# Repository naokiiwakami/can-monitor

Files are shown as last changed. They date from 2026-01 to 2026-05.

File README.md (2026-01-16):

# CAN Monitor

This is a project to build a simple CAN bus monitor.
The module uses an FTDI compatible USB to UART adapter for interface to PC
as well as power supply.

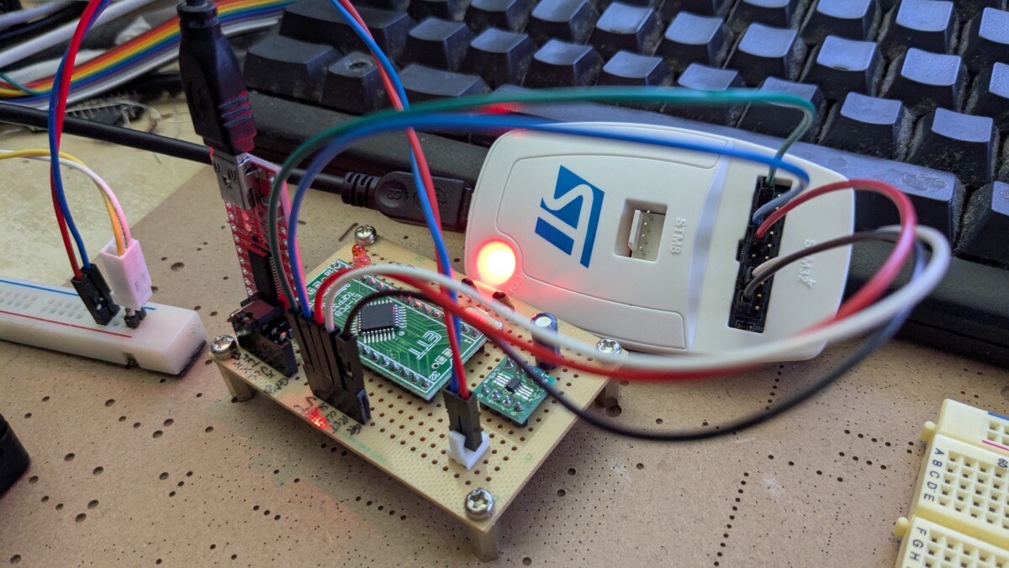
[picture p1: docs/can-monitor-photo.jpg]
module-photo


## How To Use

The adapter must support 3.3V mode as the module works
only with 3.3V supply.

Installation Steps:

- Connect the CANH and CANL ports to the CAN bus to monitor.
- Connect the USB to UART adapter dongle to the module.
- Open a terminal that supports serial interface on the host PC
(e.g. [teraterm](https://github.com/TeraTermProject/teraterm/releases)).
Configure the serial interface as following:<br />
speed: 115200<br />
data: 8 bit<br />
parity: none<br />
stop bits: 1 bit<br />
flow control: none

Then the module starts monitoring the CAN bus. Following is an example output:

```
******************************
  CAN Bus Monitor
******************************

(fb) std [ 700 ]: 03 02
(c-) ext [ 1851f42d ]: 01
(f-) std [ 700 ]: 01
```

where the flag f/c indicates whether the frame was FD or classic.
The flag b/- indicates the message was sent using Bit Rate Switching.

If you type "tx" in the terminal, the monitor sends a test classic standard
frame of identifier 0x6ad with 2-byte data [0x41, 0x26]. There is another command
which is "txfd" that sends an FD standard frame with BRS. Type "help" for more
commands.

## Firmware

STM32C092KCT6 is used for the microcontroller. The module has an SWD port and
is programmable by an ST-LINK/V2 compatible programmer.

## Schematic

A KiCAD project is available in directory `kicad/` (schematic only).

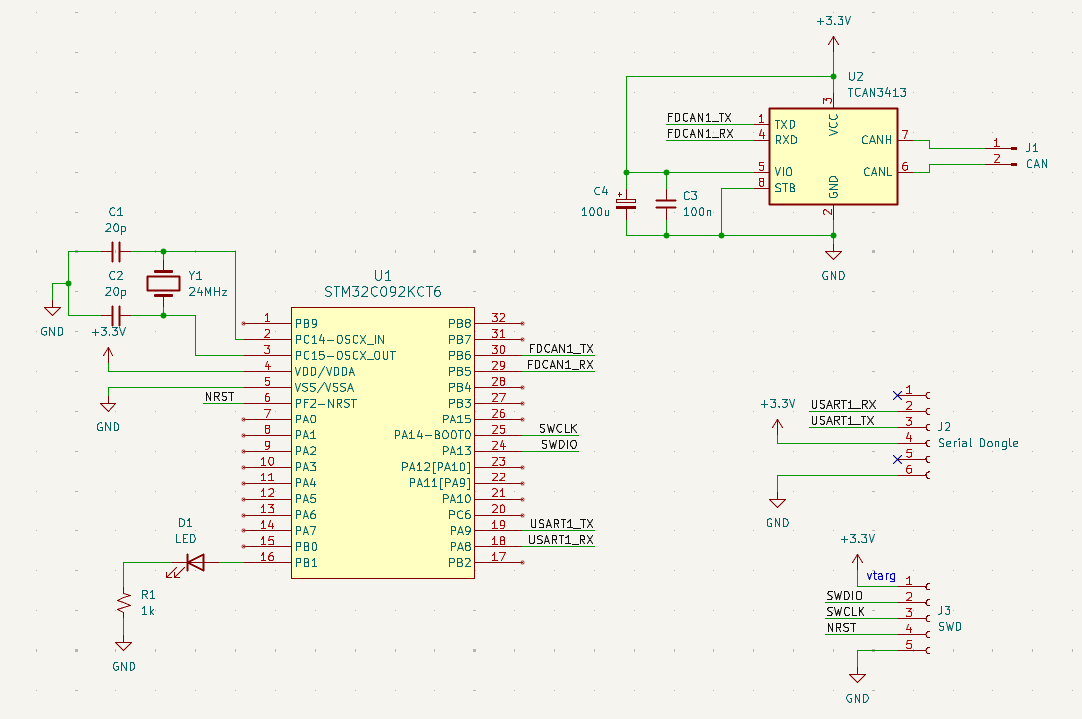
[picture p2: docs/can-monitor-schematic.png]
schematic


## TODO
- Add support for monitoring remote frames
- More user commands

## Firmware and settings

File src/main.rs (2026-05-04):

#![no_std]
#![no_main]

use core::fmt::Write;
use defmt::error;
use embassy_executor::Spawner;
use embassy_futures::select::{Either, select};
use embassy_stm32::can::{
    self, Can,
    frame::{Envelope, Header},
};
use embassy_stm32::dma;
use embassy_stm32::gpio::{Input, Level, Output, Pull, Speed};
use embassy_stm32::mode;
use embassy_stm32::peripherals;
#[cfg(feature = "hsi")]
use embassy_stm32::rcc::{Hsi, HsiKerDiv, HsiSysDiv};
use embassy_stm32::usart::{self, Uart};
use embassy_stm32::{Peripherals, bind_interrupts};
#[cfg(feature = "hse")]
use embassy_stm32::{
    rcc::{Hse, HseMode, Sysclk},
    time::Hertz,
};
use embassy_sync::{
    blocking_mutex::raw::ThreadModeRawMutex,
    channel::{Channel, Sender},
};
use embassy_time::Instant;
use embedded_can::Id;
use heapless::String;
use {defmt_rtt as _, panic_probe as _};
use {embassy_stm32::can::frame::FdFrame, embedded_can::StandardId};

static RX_CHANNEL: Channel<ThreadModeRawMutex, Envelope, 8> = Channel::new();
static TX_CHANNEL: Channel<ThreadModeRawMutex, FdFrame, 2> = Channel::new();

bind_interrupts!(struct CanIrqs {
    FDCAN1_IT0 => can::IT0InterruptHandler<peripherals::FDCAN1>;
    FDCAN1_IT1 => can::IT1InterruptHandler<peripherals::FDCAN1>;
});

bind_interrupts!(struct UsartIrqs {
    USART1 => usart::InterruptHandler<peripherals::USART1>;
    DMA1_CHANNEL2_3 => dma::InterruptHandler<peripherals::DMA1_CH2>, dma::InterruptHandler<peripherals::DMA1_CH3>;
});

async fn display_frame(
    envelope: &Envelope,
    last: &Instant,
    usart: &mut Uart<'static, mode::Async>,
) -> Result<(), usart::Error> {
    let mut log_message: String<128> = String::new();
    let interval = envelope.ts.duration_since(*last).as_micros();
    if interval > 5_000_000 {
        write!(log_message, "\r\n").unwrap();
    }
    let rx_frame = envelope.frame;
    let fd = if rx_frame.header().fdcan() { "f" } else { "c" };
    let brs = if rx_frame.header().bit_rate_switching() {
        "b"
    } else if rx_frame.header().fdcan() {
        "-"
    } else {
        " "
    };
    let timestamp = envelope.ts.as_micros();
    let ts_sec = timestamp / 1_000_000;
    let ts_msec = timestamp % 1_000_000 / 1000;
    let ts_usec = timestamp % 1000;
    match rx_frame.id() {
        Id::Standard(id) => write!(
            log_message,
            "{}.{:03}.{:03} <{}{}> std [ {:03x} ]:",
            ts_sec,
            ts_msec,
            ts_usec,
            fd,
            brs,
            id.as_raw(),
        )
        .unwrap(),
        Id::Extended(id) => write!(
            log_message,
            "{}.{:03}.{:03} <{}{}> ext [ {:08x} ]:",
            ts_sec,
            ts_msec,
            ts_usec,
            fd,
            brs,
            id.as_raw(),
        )
        .unwrap(),
    };
    for &value in &rx_frame.data()[0..rx_frame.header().len() as usize] {
        write!(log_message, " {:02x}", value).unwrap();
    }
    for _ in rx_frame.header().len() as usize..8 {
        write!(log_message, "   ").unwrap();
    }
    write!(log_message, "  ({})\r\n", interval).unwrap();
    return usart.write(log_message.as_bytes()).await;
}

async fn process_command(
    command_line: &String<128>,
    tx_sender: &mut Sender<'static, ThreadModeRawMutex, FdFrame, 2>,
    usart: &mut Uart<'static, mode::Async>,
) {
    match command_line.as_str() {
        "help" => {
            usart
                .write(b"Available commands: tx, txfd, help\r\n")
                .await
                .unwrap();
        }

        "tx" => {
            // usart.write(b"pong\r\n").await.unwrap();
            let frame = can::frame::FdFrame::new_standard(0x6ad, &[0x41, 0x26]).unwrap();
            tx_sender.send(frame).await;
        }

        "txfd" => {
            let data: [u8; 7] = [0x8a, 0xd1, 0x0a, 0xc7, 0x1b, 0x17, 0xee];
            // let data: [u8; 2] = [0x41, 0x26];
            let header = Header::new_fd(
                Id::Standard(StandardId::new(0x7df).unwrap()),
                data.len() as u8,
                false,
                true,
            );

            let frame = FdFrame::new(header, &data).unwrap();
            tx_sender.send(frame).await;
        }

        "" => {}

        _ => {
            usart.write(b"Unknown command\r\n").await.unwrap();
        }
    }
}

#[embassy_executor::task]
async fn message_consumer(mut usart: Uart<'static, mode::Async>) {
    let rx_receiver = RX_CHANNEL.receiver();
    let mut tx_sender = TX_CHANNEL.sender();
    let mut buf = [0u8; 1];
    let mut command_line: String<128> = String::new();
    let mut last = Instant::now();
    loop {
        match select(usart.read(&mut buf), rx_receiver.receive()).await {
            Either::First(out) => {
                if out.is_ok() {
                    match &buf[0] {
                        b'\r' => {
                            let temp_buf = b"\r\n";
                            usart.write(temp_buf).await.unwrap();
                            process_command(&command_line, &mut tx_sender, &mut usart).await;
                            command_line.clear();
                        }
                        _ => {
                            usart.write(&buf).await.unwrap();
                            write!(command_line, "{}", buf[0] as char).unwrap();
                        }
                    };
                }
            }
            Either::Second(envelope) => {
                display_frame(&envelope, &last, &mut usart).await.unwrap();
                last = envelope.ts;
            }
        };
    }
}

fn init() -> Peripherals {
    let mut config = embassy_stm32::Config::default();

    // configure system clock
    #[cfg(feature = "hse")]
    {
        // Set system clock source to HSE with 24 MHz crystal
        config.rcc.hse = Some(Hse {
            freq: Hertz::mhz(48),
            mode: HseMode::Oscillator,
        });
        config.rcc.sys = Sysclk::Hse;
    }

    #[cfg(feature = "hsi")]
    {
        // set system clock source to HSI with 48 MHz RC oscillation
        config.rcc.hsi = Some(Hsi {
            sys_div: HsiSysDiv::Div1,
            ker_div: HsiKerDiv::Div1,
        });
    }

    embassy_stm32::init(config)
}

async fn setup_peripherals(
    p: Peripherals,
) -> (
    Can<'static>,
    Output<'static>,
    Uart<'static, mode::Async>,
    Output<'static>,
    Output<'static>,
    Input<'static>,
) {
    let mut usart = Uart::new(
        p.USART1,
        p.PA8,
        p.PA9,
        p.DMA1_CH2,
        p.DMA1_CH3,
        UsartIrqs,
        usart::Config::default(),
    )
    .unwrap();

    usart
        .write(b"\r\n******************************\r\n")
        .await
        .unwrap();
    usart.write(b"  CAN Bus Monitor\r\n").await.unwrap();
    usart
        .write(b"******************************\r\n")
        .await
        .unwrap();

    // can standby controller pin
    let mut can_stb = Output::new(p.PB4, Level::High, Speed::Low);
    let a3_ind_red_out = Output::new(p.PB1, Level::Low, Speed::Low);
    let a3_ind_blue_out = Output::new(p.PB2, Level::Low, Speed::Low);
    let rate_select = Input::new(p.PB0, Pull::Up);

    // disable the CAN transceiver
    can_stb.set_high();

    // start the CAN controller
    let can = {
        let mut can_config = can::CanConfigurator::new(p.FDCAN1, p.PB5, p.PB6, CanIrqs);
        let nominal_bitrate = 1_000_000;
        let data_bitrate = 4_000_000;
        let mut message: String<128> = String::new();
        write!(
            message,
            "\r\nNominal bitrate : {} Mbps\r\nData bitrate    : {} Mbps\r\n\r\n",
            nominal_bitrate / 1_000_000,
            data_bitrate / 1_000_000
        )
        .unwrap();
        usart.write(message.as_bytes()).await.unwrap();
        can_config.set_bitrate(nominal_bitrate);
        can_config.set_fd_data_bitrate(data_bitrate, true);
        can_config.into_normal_mode()
    };

    // enable the CAN transceiver
    can_stb.set_low();

    usart
        .write(b"******************************\r\n")
        .await
        .unwrap();
    (
        can,
        can_stb,
        usart,
        a3_ind_red_out,
        a3_ind_blue_out,
        rate_select,
    )
}

#[embassy_executor::main]
async fn main(_spawner: Spawner) {
    let p = init();
    let (mut can, mut _can_stb, usart, mut _a3_ind_red, mut _a3_ind_blue, _rate_select) =
        setup_peripherals(p).await;

    _spawner.spawn(message_consumer(usart).unwrap());

    let rx_sender = RX_CHANNEL.sender();
    let tx_receiver = TX_CHANNEL.receiver();
    loop {
        match select(can.read(), tx_receiver.receive()).await {
            Either::First(read_result) => match read_result {
                Ok(envelope) => {
                    rx_sender.send(envelope).await;
                }
                Err(err) => {
                    error!("Error in frame: {:?}", err);
                    break;
                }
            },
            Either::Second(tx_frame) => {
                _ = can.write_fd(&tx_frame).await;
            }
        }
    }
}

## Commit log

2026-01-15 Support bit rate switching
2026-01-16 Add a feature to display FDF and BRS frame header flags
2026-04-23 switch and upgrade depending embassy repository
2026-05-04 Add capability to print timestamps
